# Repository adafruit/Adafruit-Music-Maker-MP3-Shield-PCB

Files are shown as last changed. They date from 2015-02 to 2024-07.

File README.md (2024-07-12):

# Adafruit Music Maker MP3 Shields PCB

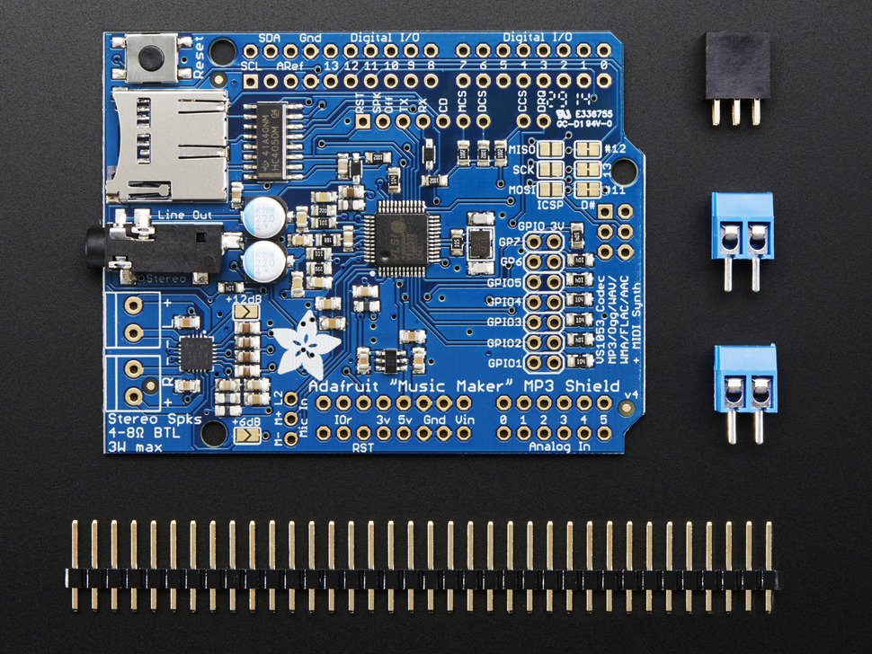
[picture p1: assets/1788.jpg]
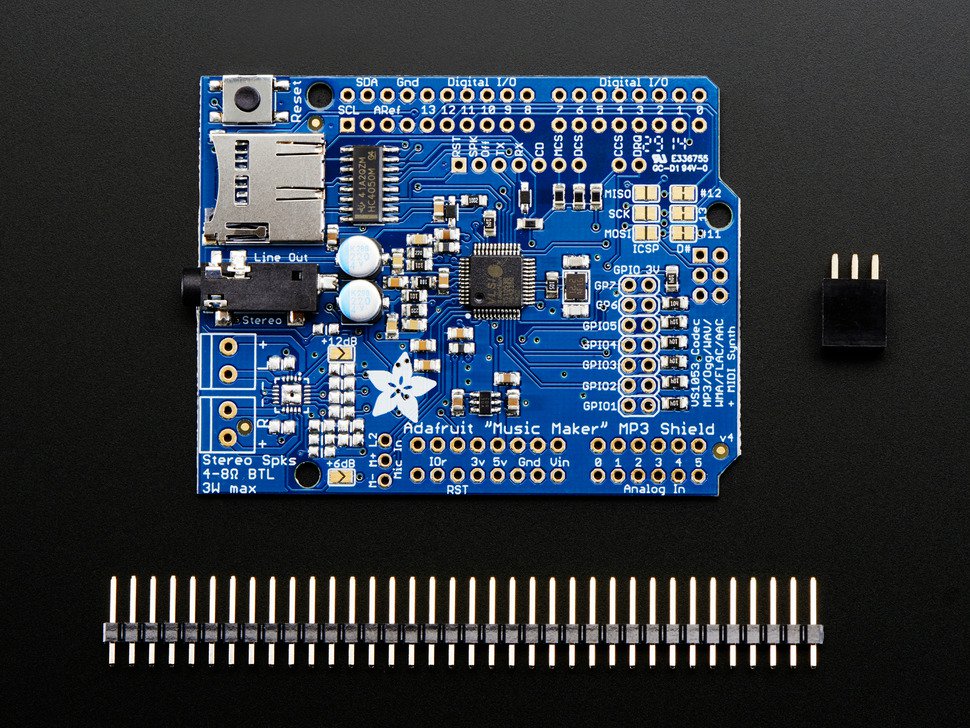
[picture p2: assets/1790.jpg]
&nbsp; <br />
Click to purchase from the Adafruit Shop:
- [With 3W Amp](https://www.adafruit.com/product/1788)
- [Without 3W Amp](https://www.adafruit.com/product/1790)

These powerful shields feature the VS1053, an encoding/decoding (codec) chip that can decode a wide variety of audio formats such as MP3, AAC, Ogg Vorbis, WMA, MIDI, FLAC, WAV (PCM and ADPCM). They can also be used to record audio in both PCM (WAV) and compressed Ogg Vorbis. You can do all sorts of stuff with the audio as well such as adjusting bass, treble, and volume digitally.

All this functionality is implemented in a light-weight SPI interface so that any Arduino can play audio from an SD card. There's also a special MIDI mode that you can boot the chip into that will read 'classic' 31250Kbaud MIDI data from an Arduino pin and act like a synth/drum machine - there are dozens of built-in drum and sample effects! But the chip is a pain to solder, and needs a lot of extras. That's why we spun up the best shields, perfect for use with any Adafruit Metro or Arduino Uno, Leonardo or Mega.

There are two versions of the shield: the first has stereo line/headphone output. There is also a version with a 3W/channel class-D stereo speaker amplifier for easy use in projects that need to be loud.

Yjis repo contains PCB files for the Adafruit Music Maker VS1053 (MP3/MIDI/WAV/Ogg...) Shields for Arduino

Format is EagleCAD schematic and board layout

For more details, check out the product pages at

-----> https://www.adafruit.com/product/1788

-----> https://www.adafruit.com/product/1790

Revision history:

* As of Aug 23, 2023 - we've updated this PCB with Adafruit Pinguin to make a lovely and legible silkscreen. We've also updated the music maker to use the 2x3 SPI header instead of pins 11/12/13  and the terminal blocks now come pre-soldered on.
* Aug 20, 2014: We updated the analog section to have more filtering, which should improve audio output quality (even more!) There are no wiring or code changes.

### License

Adafruit invests time and resources providing this open source design, please support Adafruit and open-source hardware by purchasing products from [Adafruit](https://www.adafruit.com)!

All text above must be included in any redistribution

Designed by Limor Fried/Ladyada for Adafruit Industries.
Creative Commons Attribution/Share-Alike, all text above must be included in any redistribution. 
See license.txt for additional information.

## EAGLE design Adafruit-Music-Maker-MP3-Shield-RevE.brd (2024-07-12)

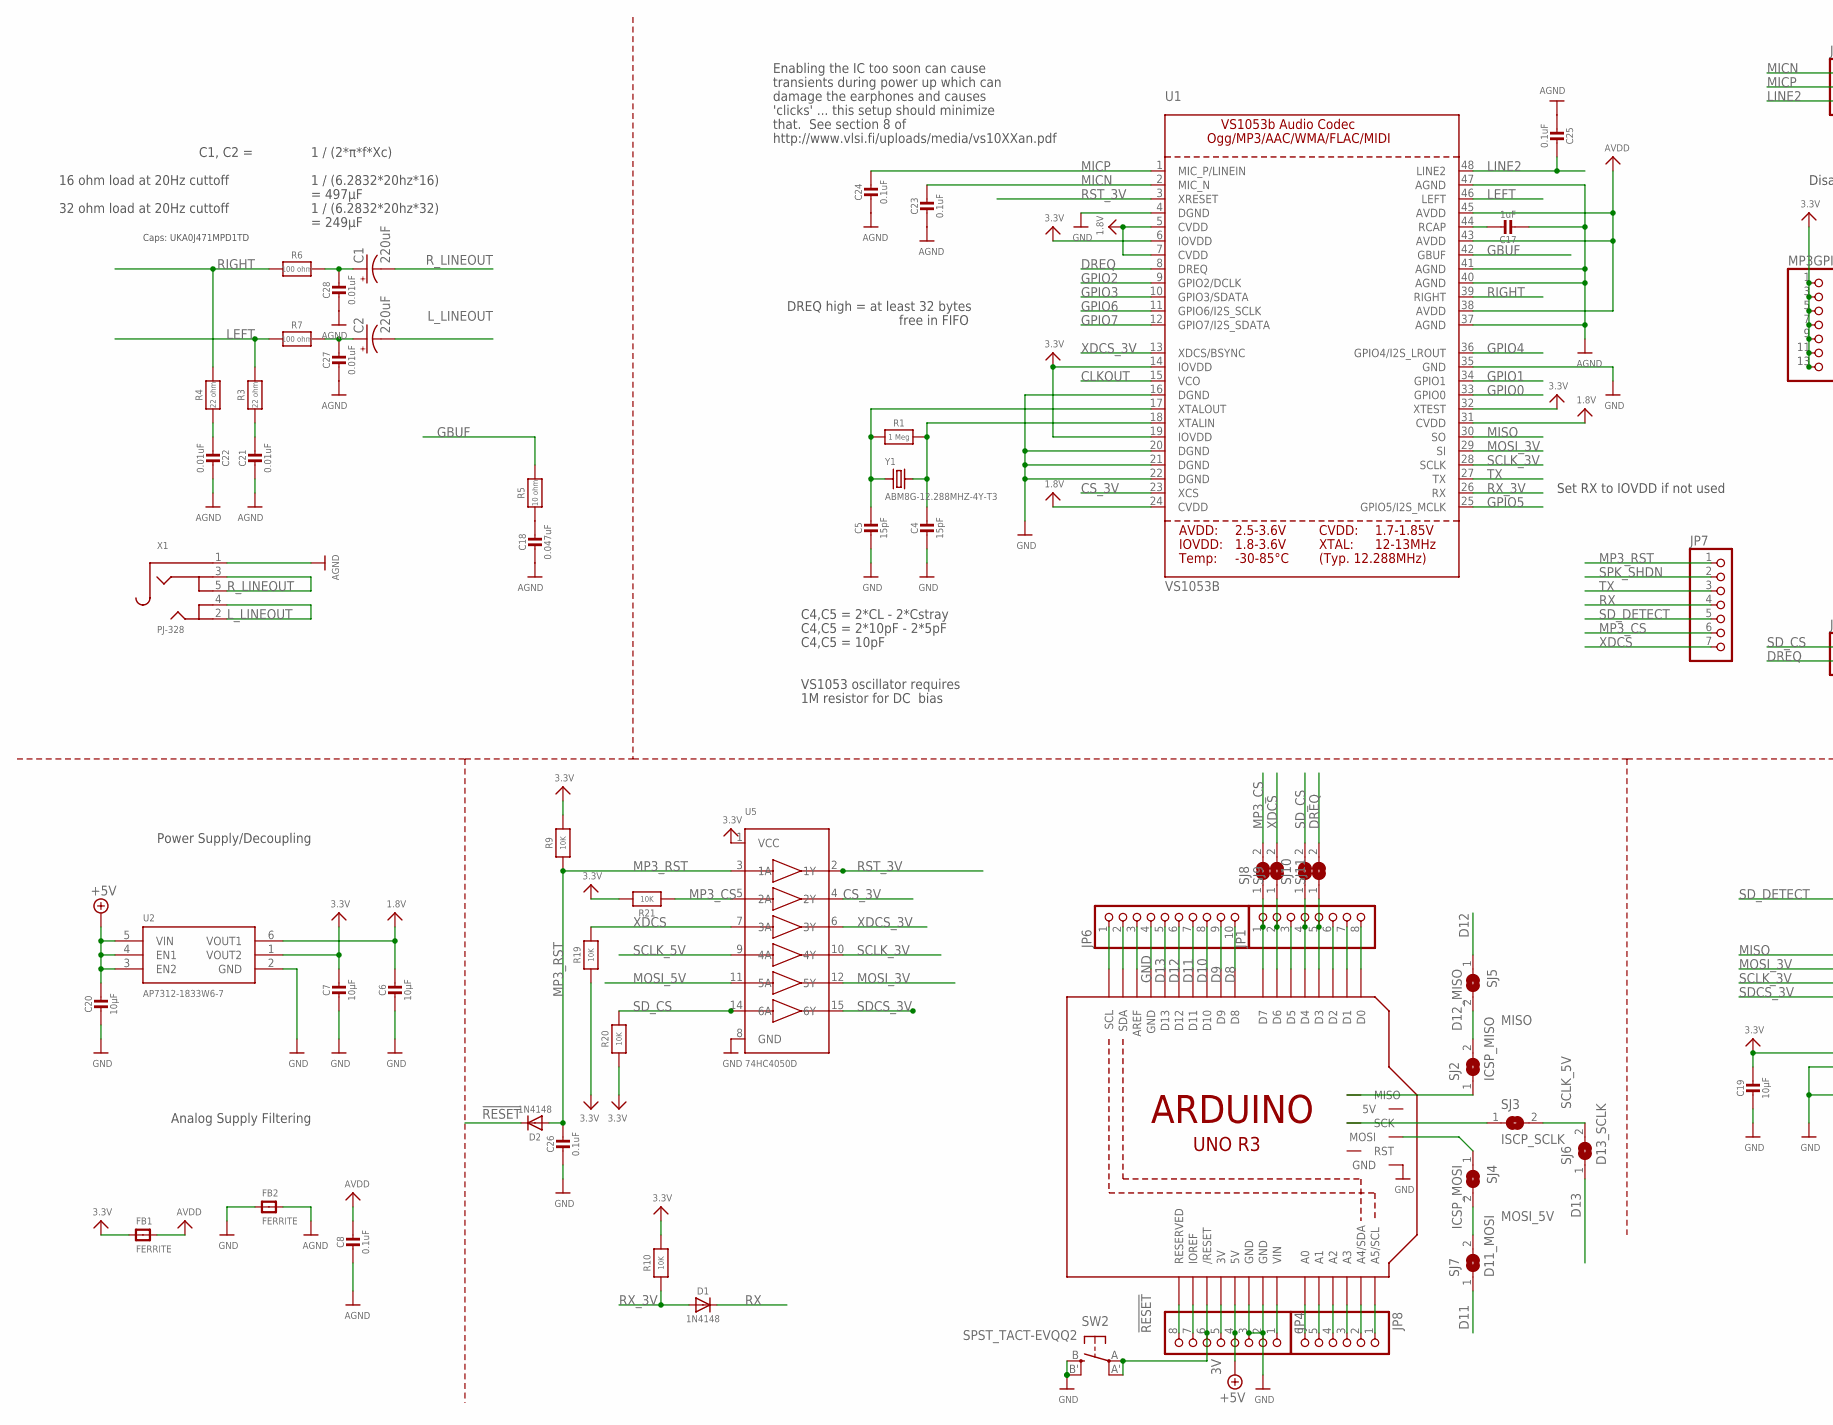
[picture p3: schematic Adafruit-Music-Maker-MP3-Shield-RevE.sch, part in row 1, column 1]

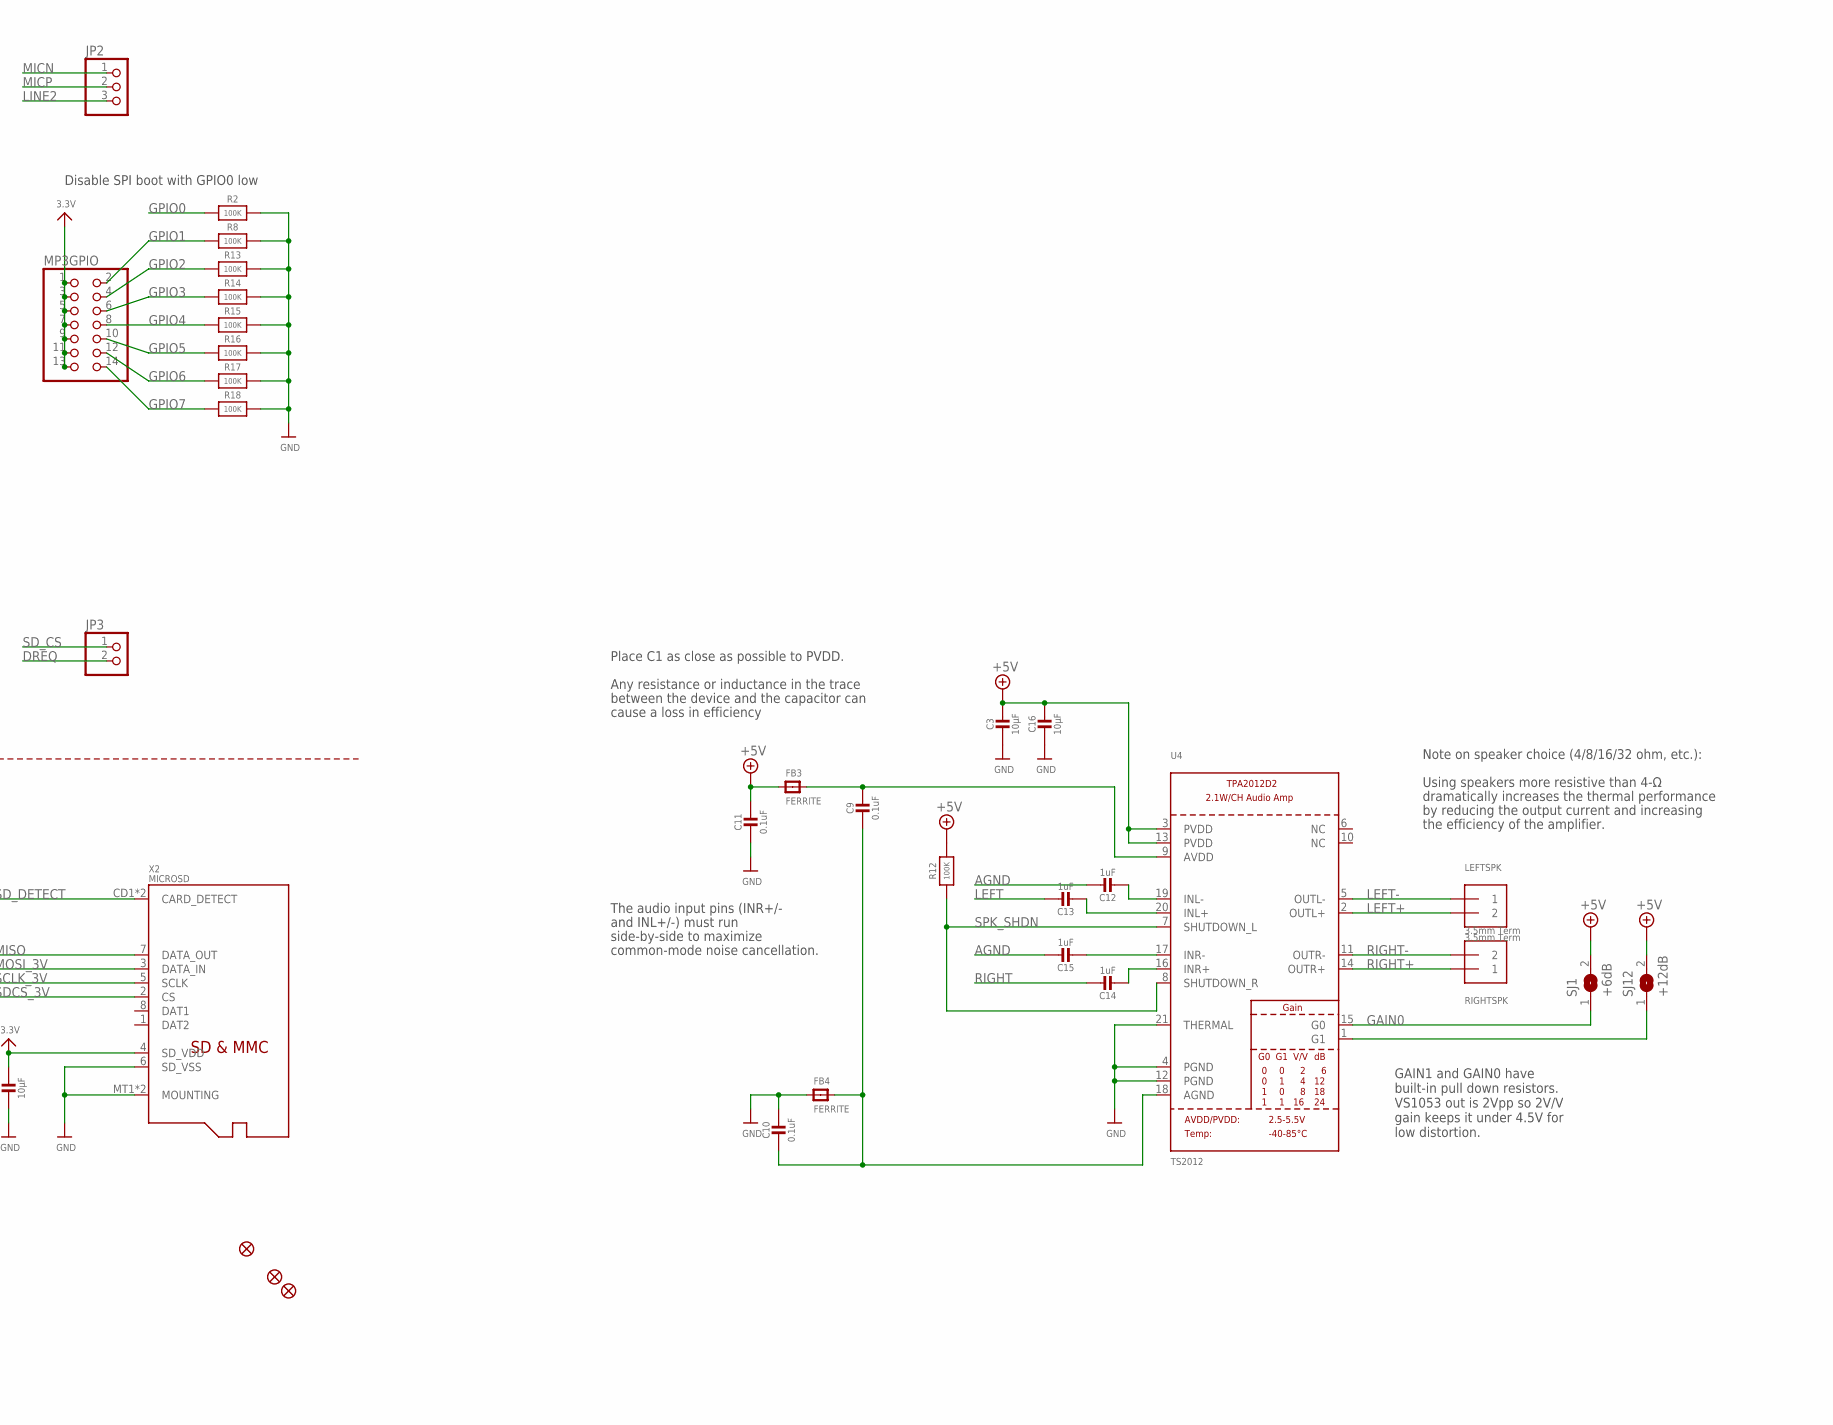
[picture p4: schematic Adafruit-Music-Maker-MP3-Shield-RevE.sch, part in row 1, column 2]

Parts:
C1, C2: 220uF; PANASONIC_C
C3, C6, C7, C16, C19, C20: 10µF; 0805-NO
C4, C5: 15pF; 0603-NO
C8, C9, C10, C11, C23, C24, C25, C26: 0.1uF; 0603-NO
C12, C13, C14, C15, C17: 1uF; 0603-NO
C18: 0.047uF; 0603-NO
C21, C22, C27, C28: 0.01uF; 0603-NO
D1, D2: 1N4148; SOD-323
FB1, FB2, FB3, FB4: FERRITE; 0603-NO
FID1, FID2, FID3: FIDUCIAL_1MM
JP1, JP4: PINHD-1X8CLEANBIG; 1X08-CLEANBIG
JP2: PINHD-1X3CB; 1X03-CLEANBIG
JP3: HEADER-1X2ROUND; 1X02_ROUND
JP6: HEADER-1X1070MIL; 1X10_ROUND70
JP7: HEADER-1X770MIL; 1X07_ROUND_70
JP8: PINHD-1X6CB; 1X06-CLEANBIG
LEFTSPK: 3.5mm Term; TERMBLOCK_1X2-3.5MM
MP3GPIO: HEADER-2X7_ROUND_70MIL; 2X07_ROUND_70MIL
R1: 1 Meg; 0603-NO
R2, R8, R12, R13, R14, R15, R16, R17, R18: 100K; 0603-NO
R3, R4: 22 ohm; 0603-NO
R5: 10 ohm; 0603-NO
R6, R7: 100 ohm; 0603-NO
R9, R10, R19, R20, R21: 10K; 0603-NO
RIGHTSPK: 3.5mm Term; TERMBLOCK_1X2-3.5MM
SJ1: +6dB; SOLDERJUMPER_ARROW_NOPASTE
SJ2: ICSP_MISO; SOLDERJUMPER_CLOSEDWIRE
SJ3: ISCP_SCLK; SOLDERJUMPER_CLOSEDWIRE
SJ4: ICSP_MOSI; SOLDERJUMPER_CLOSEDWIRE
SJ5: D12_MISO; SOLDERJUMPER_ARROW_NOPASTE
SJ6: D13_SCLK; SOLDERJUMPER_ARROW_NOPASTE
SJ7: D11_MOSI; SOLDERJUMPER_ARROW_NOPASTE
SJ8, SJ9, SJ10, SJ11: SOLDERJUMPERCLOSED; SOLDERJUMPER_CLOSEDWIRE
SJ12: +12dB; SOLDERJUMPER_ARROW_NOPASTE
SW2: SPST_TACT-EVQQ2; EVQ-Q2
U1: VS1053B; LQFP48
U2: AP7312-1833W6-7; SOT23-6
U4: TS2012; WQFN20
U5: 74HC4050D; SOIC16
U$41: ARDUINO_R3_ICSP; ARDUINOR3_ICSP
X1: PJ-328; PJ-328-5
X2: MICROSD
Y1: ABM8G-12.288MHZ-4Y-T3; CRYSTAL_3.2X2.5

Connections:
1.8V: C6.1, U1.5 (CVDD), U1.7 (CVDD), U1.24 (CVDD), U1.31 (CVDD), U2.6 (VOUT1)
3.3V: C7.1, C19.1, FB1.1, MP3GPIO.1, MP3GPIO.3, MP3GPIO.5, MP3GPIO.7, MP3GPIO.9, MP3GPIO.11, MP3GPIO.13, R9.2, R10.2, R19.1, R20.1, R21.2, U1.6 (IOVDD), U1.14 (IOVDD), U1.19 (IOVDD), U1.32 (XTEST), U2.1 (VOUT2), U5.1 (VCC), X2.4 (SD_VDD)
3V: JP4.5, U$41.3V
!RESET: D2.C, JP4.6, SW2.A, SW2.A' (P1), U$41.RESET (/RESET)
+5V: C3.1, C11.1, C16.1, C20.1, FB3.1, JP4.4, R12.2, SJ1.2, SJ12.2, U2.3 (EN2), U2.4 (EN1), U2.5 (VIN), U4.3 (PVDD), U4.13 (PVDD), U$41.5V
A0: JP8.6, U$41.A0
A1: JP8.5, U$41.A1
A2: JP8.4, U$41.A2
A3: JP8.3, U$41.A3
A4: JP8.2, U$41.A4 (A4/SDA)
A5: JP8.1, U$41.A5 (A5/SCL)
AGND: C8.2, C12.1, C15.1, C17.2, C18.2, C21.2, C22.2, C23.2, C24.2, C25.2, C27.2, C28.2, FB2.2, U1.37 (AGND), U1.40 (AGND), U1.41 (AGND), U1.47 (AGND), X1.1
AREF: JP6.3, U$41.AREF
AVDD: C8.1, FB1.2, U1.38 (AVDD), U1.43 (AVDD), U1.45 (AVDD)
CLKOUT: U1.15 (VCO)
CS_3V: U1.23 (XCS), U5.4 (2Y)
D0: JP1.8, U$41.D0
D1: JP1.7, U$41.D1
D2: JP1.6, U$41.D2
D3: JP1.5, SJ11.1, U$41.D3
D4: JP1.4, SJ10.1, U$41.D4
D5: JP1.3, U$41.D5
D6: JP1.2, SJ9.1, U$41.D6
D7: JP1.1, SJ8.1, U$41.D7
D8: JP6.10, U$41.D8
D9: JP6.9, U$41.D9
D10: JP6.8, U$41.D10
D11: JP6.7, SJ7.1, U$41.D11
D12: JP6.6, SJ5.1, U$41.D12
D13: JP6.5, SJ6.1, U$41.D13
DREQ: JP3.2, SJ11.2, U1.8 (DREQ)
GAIN0: SJ1.1, U4.15 (G0)
GBUF: R5.1, U1.42 (GBUF)
GND: C3.2, C4.2, C5.2, C6.2, C7.2, C10.1, C11.2, C16.2, C19.2, C20.2, C26.2, FB2.1, FB4.1, JP4.2, JP4.3, JP6.4, R2.2, R8.2, R13.2, R14.2, R15.2, R16.2, R17.2, R18.2, SW2.B (S), SW2.B' (S1), U1.4 (DGND), U1.16 (DGND), U1.20 (DGND), U1.21 (DGND), U1.22 (DGND), U1.35 (GND), U2.2 (GND), U4.4 (PGND), U4.12 (PGND), U4.21 (THERMAL), U5.8 (GND), U$41.GND, U$41.GND@1 (GND), U$41.GND@2 (GND), U$41.GND@3 (GND), X2.6 (SD_VSS), X2.MT1 (MOUNTING), X2.MT2 (MOUNTING)
GPIO0: R2.1, U1.33 (GPIO0)
GPIO1: MP3GPIO.2, R8.1, U1.34 (GPIO1)
GPIO2: MP3GPIO.4, R13.1, U1.9 (GPIO2/DCLK)
GPIO3: MP3GPIO.6, R14.1, U1.10 (GPIO3/SDATA)
GPIO4: MP3GPIO.8, R15.1, U1.36 (GPIO4/I2S_LROUT)
GPIO5: MP3GPIO.10, R16.1, U1.25 (GPIO5/I2S_MCLK)
GPIO6: MP3GPIO.12, R17.1, U1.11 (GPIO6/I2S_SCLK)
GPIO7: MP3GPIO.14, R18.1, U1.12 (GPIO7/I2S_SDATA)
IOREF: JP4.7, U$41.IOREF
LEFT: C13.1, R3.1, R7.2, U1.46 (LEFT)
LEFT+: LEFTSPK.2, U4.2 (OUTL+)
LEFT-: LEFTSPK.1, U4.5 (OUTL-)
LEFT_FILTERED: C2.+, C27.1, R7.1
LINE2: C25.1, JP2.3, U1.48 (LINE2)
L_LINEOUT: C2.-, X1.2, X1.4
MICN: C23.1, JP2.1, U1.2 (MIC_N)
MICP: C24.1, JP2.2, U1.1 (MIC_P/LINEIN)
MISO: SJ2.2, SJ5.2, U1.30 (SO), X2.7 (DATA_OUT)
MISO_ICSP: SJ2.1, U$41.MISO
MOSI_3V: U1.29 (SI), U5.12 (5Y), X2.3 (DATA_IN)
MOSI_5V: SJ4.2, SJ7.2, U5.11 (5A)
MOSI_ICSP: SJ4.1, U$41.MOSI
MP3_CS: JP7.6, R21.1, SJ8.2, U5.5 (2A)
MP3_RST: C26.1, D2.A, JP7.1, R9.1, U5.3 (1A)
unnamed: C5.1, R1.1, U1.17 (XTALOUT), Y1.1
unnamed: C4.1, R1.2, U1.18 (XTALIN), Y1.2
unnamed: C21.1, R3.2
unnamed: C22.1, R4.2
unnamed: C13.2, U4.20 (INL+)
unnamed: C12.2, U4.19 (INL-)
unnamed: C15.2, U4.17 (INR-)
unnamed: C14.2, U4.16 (INR+)
unnamed: C9.2, C10.2, FB4.2, U4.18 (AGND)
unnamed: C9.1, FB3.2, U4.9 (AVDD)
unnamed: SJ12.1, U4.1 (G1)
unnamed: C17.1, U1.44 (RCAP)
unnamed: C18.1, R5.2
NC: JP4.8, U$41.RESERVED
RIGHT: C14.1, R4.1, R6.2, U1.39 (RIGHT)
RIGHT+: RIGHTSPK.1, U4.14 (OUTR+)
RIGHT-: RIGHTSPK.2, U4.11 (OUTR-)
RIGHT_FILTERED: C1.+, C28.1, R6.1
RST_3V: U1.3 (XRESET), U5.2 (1Y)
RX: D1.C, JP7.4
RX_3V: D1.A, R10.1, U1.26 (RX)
R_LINEOUT: C1.-, X1.3, X1.5
SCK_ICSP: SJ3.1, U$41.SCK
SCL: JP6.1, U$41.SCL
SCLK_3V: U1.28 (SCLK), U5.10 (4Y), X2.5 (SCLK)
SCLK_5V: SJ3.2, SJ6.2, U5.9 (4A)
SDA: JP6.2, U$41.SDA
SDCS_3V: U5.15 (6Y), X2.2 (CS)
SD_CS: JP3.1, R20.2, SJ10.2, U5.14 (6A)
SD_DETECT: JP7.5, X2.CD1 (CARD_DETECT), X2.CD2 (CARD_DETECT)
SPK_SHDN: JP7.2, R12.1, U4.7 (SHUTDOWN_L), U4.8 (SHUTDOWN_R)
TX: JP7.3, U1.27 (TX)
VIN: JP4.1, U$41.VIN
XDCS: JP7.7, R19.2, SJ9.2, U5.7 (3A)
XDCS_3V: U1.13 (XDCS/BSYNC), U5.6 (3Y)

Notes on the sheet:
Analog Supply Filtering
C4,C5 = 2*CL - 2*Cstray
C4,C5 = 2*10pF - 2*5pF
C4,C5 = 10pF
VS1053 oscillator requires
1M resistor for DC bias
Set RX to IOVDD if not used
DREQ high = at least 32 bytes
Power Supply/Decoupling
transients during power up which can
damage the earphones and causes
'clicks' ... this setup should minimize
that. See section 8 of
http://www.vlsi.fi/uploads/media/vs10XXan.pdf
Enabling the IC too soon can cause
free in FIFO
Disable SPI boot with GPIO0 low
1 / (2*π*f*Xc)
16 ohm load at 20Hz cuttoff
1 / (6.2832*20hz*16)
C1, C2 =
= 497µF
32 ohm load at 20Hz cuttoff
1 / (6.2832*20hz*32)
= 249µF
Caps: UKA0J471MPD1TD
GAIN1 and GAIN0 have built-in pull down resistors. VS1053 out is 2Vpp so 2V/V gain keeps it under 4.5V for low distortion.
Place C1 as close as possible to PVDD.
Any resistance or inductance in the trace
between the device and the capacitor can
cause a loss in efficiency
Using speakers more resistive than 4-Ω
dramatically increases the thermal performance
by reducing the output current and increasing
the efficiency of the amplifier.
Note on speaker choice (4/8/16/32 ohm, etc.):
The audio input pins (INR+/-
and INL+/-) must run
side-by-side to maximize
common-mode noise cancellation.

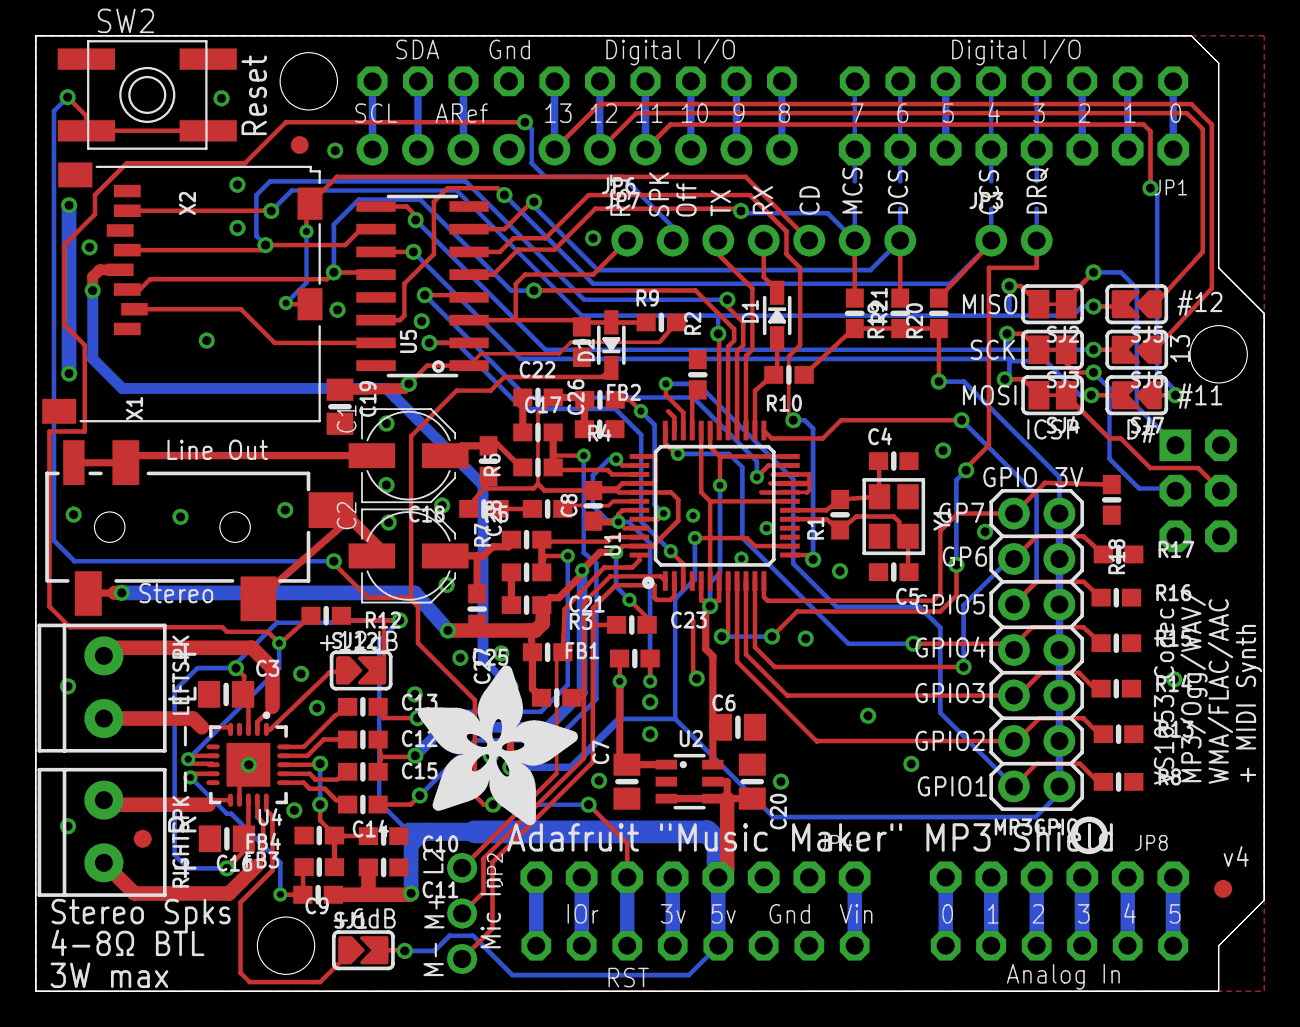
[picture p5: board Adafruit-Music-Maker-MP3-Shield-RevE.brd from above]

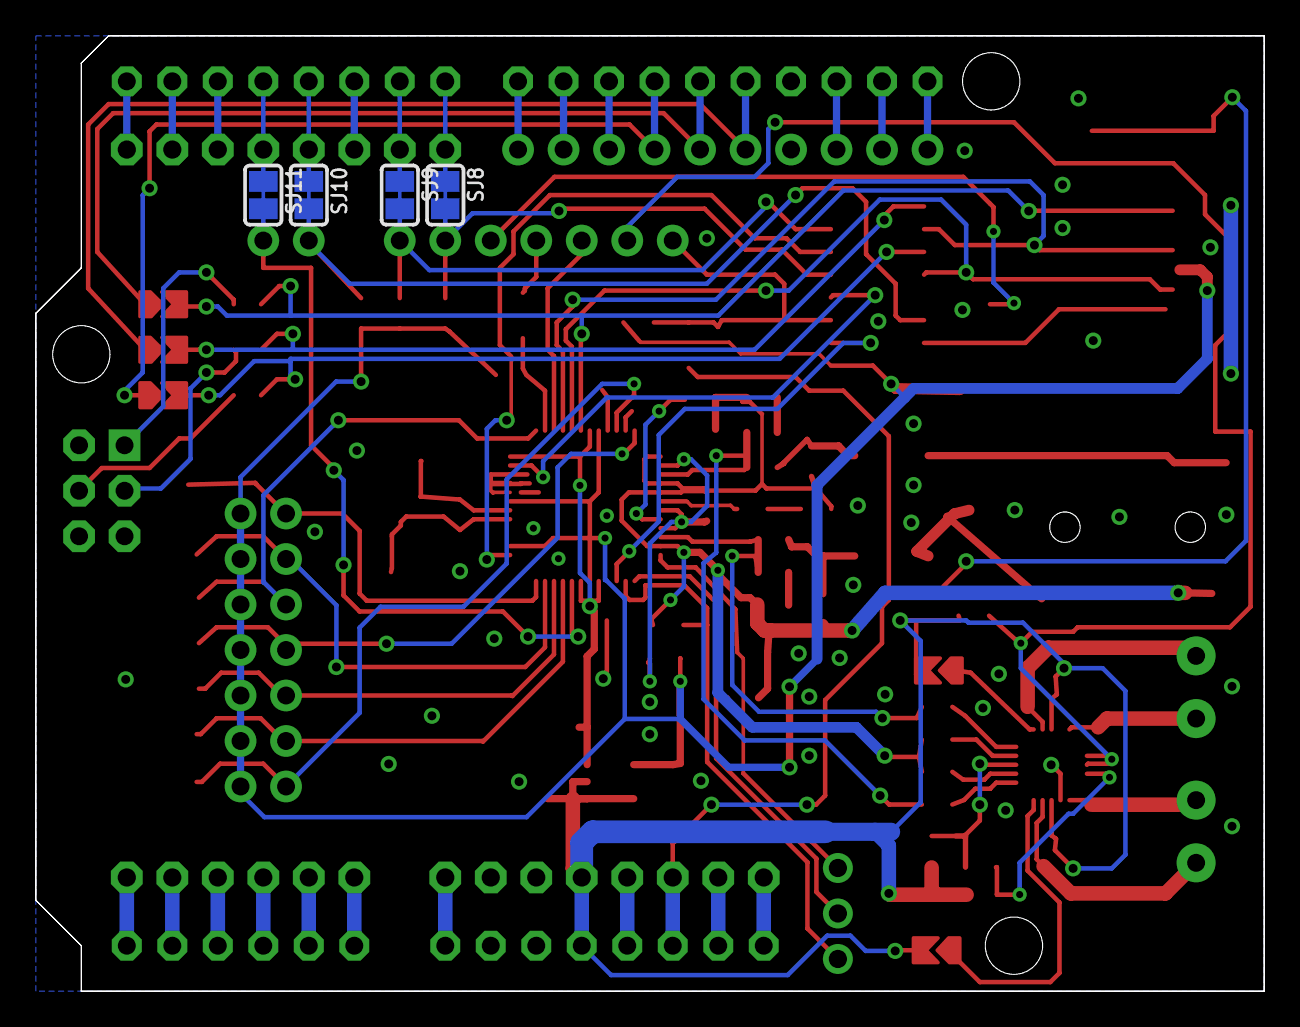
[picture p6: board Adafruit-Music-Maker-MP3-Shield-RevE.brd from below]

Board: 2 copper layers, 68.6 x 53.3 mm, 90 parts (4 on the bottom side), 92 nets.

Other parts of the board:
U$50: ADAFRUIT_9MM
U$57: PCBFEAT-REV-040
